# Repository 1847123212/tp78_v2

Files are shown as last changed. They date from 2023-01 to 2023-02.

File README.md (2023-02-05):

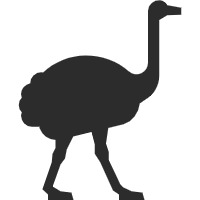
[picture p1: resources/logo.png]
MarkText


<h1 align="center">TrackPoint78 </h1>

TrackPoint78是基于CH582M的三模机械键盘方案。

V2.0新特性：

1. 支持USB U盘改键和配置

2. 支持触摸板触摸条操作

3. 集成USB hub接口

4. 增加I2C磁吸扩展口

5. 集成RF模式和接收器方案

6. 增加I2C小红点方案

7. 增加触摸条震动反馈

8. 优化OELD UI

9. 增加Fn+B进BootLoader功能

10. 增加待机自动进lowpower模式

11. ...

### 仓库目录

```mermaid
flowchart LR

A(repository) --> B(documents - 手册和文档)
A(repository) --> C(mounriver_project - wch软件工程)
A(repository) --> D(pcb_project - PCB工程)
A(repository) --> E(solidworks_project - 模型相关文件)
A(repository) --> F(tools - 相关辅助工具)
C(mounriver_project - wch软件工程) --> G(BLE_CH582M - 三模无线键盘工程)
C(mounriver_project - wch软件工程) --> H(RF_CH582M - 配套接收器工程)
C(mounriver_project - wch软件工程) --> I(CH582M - 单模USB旧工程, 用来测试)
```

### 软件工程目录

```mermaid
flowchart LR

A(BLE_582M) --> B(APP - 应用层)
A(BLE_582M) --> C(HAL - HAL层, 包含各种驱动接口)
A(BLE_582M) --> D(Ld - 链接文件)
A(BLE_582M) --> E(LIB - 存放WCH蓝牙闭源库)
A(BLE_582M) --> F(Packages - 第三方开源包)
A(BLE_582M) --> G(Profile - 蓝牙服务相关)
A(BLE_582M) --> H(RVMSIS - RISC V相关指令)
A(BLE_582M) --> I(Startup - CH582M启动文件)
A(BLE_582M) --> J(StdPeriphDriver - CH582M库函数)
```

### 关于固件升级Q&A

- **Q**: 如何进入BOOTLOADER？

- **A:** 按住底板中BOOT键通电，或按下Fn+B进入BOOTLOADER。注意：Fn+B后会擦除部分CodeFlash部分片段，上电后必须先下载程序。

- **Q:** 如何升级固件？

- **A:** 使用WCH官方ISP工具进行固件升级，工具目录：tools/WCHISPTool/WCHISPTool.exe。
  
  > - 选择CH58x系列；
  > 
  > - 在USB设备列表里找到自己的设备，若找不到尝试重新进入BOOT；
  > 
  > - 根据需求勾选相关下载配置，若不确定可进行咨询，一般使用默认配置即可；
  > 
  > - 选择用户程序文件；
  > 
  > - 最后点击下载。

- **Q:** 多次点击下载后，进度条跑完显示失败。

- **A:** 建议更换核心板。

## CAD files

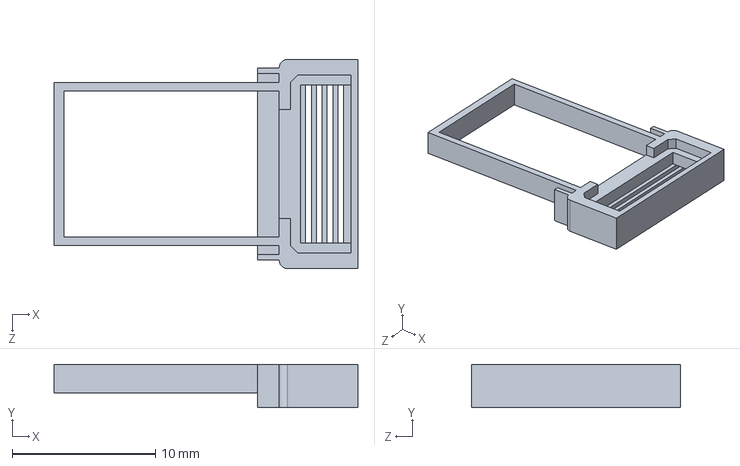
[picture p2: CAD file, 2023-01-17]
solidworks_project/RF接收器_底座.SLDPRT
21.2 x 3.00 x 14.6 mm

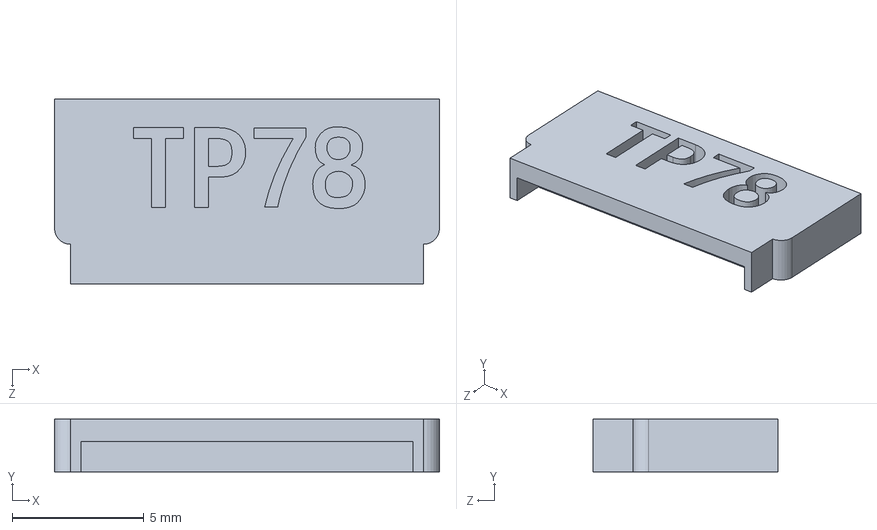
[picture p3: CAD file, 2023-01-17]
solidworks_project/RF接收器_上盖.SLDPRT
14.6 x 2.00 x 7.00 mm

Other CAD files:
solidworks_project/RF接收器_上盖.STL
solidworks_project/RF接收器_底座.STL

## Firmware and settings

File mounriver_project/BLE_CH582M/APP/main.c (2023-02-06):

/********************************** (C) COPYRIGHT *******************************
* File Name          : main.c
* Author             : ChnMasterOG, WCH
* Version            : V2.0
* Date               : 2022/11/30
* Description        : 应用层 - TP78小红点+蓝牙+2.4G三模键盘应用主函数及任务系统初始化
* Copyright (c) 2021 Nanjing Qinheng Microelectronics Co., Ltd.
* SPDX-License-Identifier: GPL-3.0
*******************************************************************************/

/********************************** (C) COPYRIGHT *******************************
 *  Pin information:
 *  PB10 & PB11 --- USB1_D-/USB1_D+; [PA0~PA7 & PA9 & PA11~PA15] & [PB0/PB1/PB2/PB3/PB5/PB6] --- KeyBoard
 *  PB15(*) & PB14 --- PS/2 Reserved; PA10 --- WS2812(TMR1); PB13 & PB12 --- SCL/SDA
 *  PA8 --- Battery ADC; PB16 & PB17 --- Battery COM/CHRG; PB7 & PB4 --- TXD0/RXD0;
 *  PB21 & PB20 ---TXD3_/RXD3_; PB15(*) --- I2C TrackPoint IRQ; PB18 --- MPR121 IRQ; PB19 --- Motor CTL
 ********************************* (C) COPYRIGHT ********************************/

/*********************************************************************
 * INCLUDES
 */
#include "HAL.h"
#include "CONFIG.h"
#include "CH58x_common.h"
#include "hiddev.h"

/*********************************************************************
 * GLOBAL TYPEDEFS
 */
__attribute__((aligned(4))) u32 MEM_BUF[BLE_MEMHEAP_SIZE/4];

#if (defined (BLE_MAC)) && (BLE_MAC == TRUE)
u8C MacAddr[6] = {0x84,0xC2,0xE4,0x03,0x02,0x02};
#endif

/*******************************************************************************
* Function Name  : Main_Circulation
* Description    : 主循环
* Input          : None
* Output         : None
* Return         : None
*******************************************************************************/
__HIGH_CODE
void Main_Circulation()
{
  // 开启TMOS任务调度
  while(1){
    TMOS_SystemProcess( );
  }
}

/*******************************************************************************
* Function Name  : main
* Description    : 主函数
* Input          : None
* Output         : None
* Return         : None
*******************************************************************************/
int main( void )
{
#if (defined (DCDC_ENABLE)) && (DCDC_ENABLE == TRUE)
  PWR_DCDCCfg( ENABLE );
#endif
  SetSysClock( CLK_SOURCE_PLL_60MHz );
#if (defined (HAL_SLEEP)) && (HAL_SLEEP == TRUE)
  GPIOA_ModeCfg( GPIO_Pin_All, GPIO_ModeIN_PU );
  GPIOB_ModeCfg( GPIO_Pin_All, GPIO_ModeIN_PU );
#endif
#ifdef DEBUG  // DEBUG = 3(use UART3)
  GPIOB_SetBits(GPIO_Pin_21);
  GPIOB_ModeCfg(GPIO_Pin_20, GPIO_ModeIN_PU);       // RXD-配置上拉输入
  GPIOB_ModeCfg(GPIO_Pin_21, GPIO_ModeOut_PP_5mA);  // TXD-配置推挽输出，注意先让IO口输出高电平
  GPIOPinRemap(ENABLE, RB_PIN_UART3);
  UART3_DefInit();
#endif
  PRINT("%s\n",VER_LIB);
  CH58X_BLEInit( );
  HAL_Init( );
#if (defined (HAL_RF)) && (HAL_RF == TRUE)
  if (g_Ready_Status.rf == FALSE) {
#endif
    GAPRole_PeripheralInit( );
    HidDev_Init( );
    HidEmu_Init( );
#if (defined (HAL_RF)) && (HAL_RF == TRUE)
  } else {
    RF_RoleInit();
    RF_Init();
  }
#endif
  tmos_start_task( halTaskID, MAIN_CIRCULATION_EVENT, 10 ); // 主循环
  tmos_start_task( halTaskID, WS2812_EVENT, 10 );  // 背光控制
  tmos_start_task( halTaskID, OLED_UI_EVENT, 10 );  // OLED UI
#if ((defined HAL_MPR121_CAPMOUSE) && (HAL_MPR121_CAPMOUSE == TRUE)) || ((defined HAL_MPR121_TOUCHBAR) && (HAL_MPR121_TOUCHBAR == TRUE))
  tmos_start_task( halTaskID, MPR121_EVENT, 10 );  // MPR121
#endif
  tmos_start_task( halTaskID, SYST_EVENT, 10 );  // 系统定时
  Main_Circulation();
}

/*******************************************************************************
* Function Name  : GPIOA_IRQHandler
* Description    : GPIOA外部中断
* Input          : None
* Return         : None
*******************************************************************************/
__INTERRUPT
__HIGH_CODE
void GPIOA_IRQHandler(void)
{
#if (defined MSG_CP) && (MSG_CP == TRUE)
  CP_WAKEUP_GPIO(SetBits)( CP_WAKEUP_PIN );   // 唤醒CP
  g_Ready_Status.cp = FALSE;
  tmos_start_task( halTaskID, CP_INITIAL_EVENT, MS1_TO_SYSTEM_TIME(300) );  // CP重新上电
#endif
  GPIOA_ClearITFlagBit(Colum_Pin_ALL);  // 用于唤醒
}

/*******************************************************************************
* Function Name  : GPIOB_IRQHandler
* Description    : GPIOB外部中断
* Input          : None
* Return         : None
*******************************************************************************/
__INTERRUPT
__HIGH_CODE
void GPIOB_IRQHandler( void )
{
#if (defined HAL_PS2) && (HAL_PS2 == TRUE)
  PS2_IT_handler();
#endif
#if (defined HAL_I2C_TP) && (HAL_I2C_TP == TRUE)
  I2C_TP_IT_handler();
#endif
}

/******************************** endfile @ main ******************************/

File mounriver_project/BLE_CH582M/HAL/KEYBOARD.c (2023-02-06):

/********************************** (C) COPYRIGHT *******************************
 * File Name          : KEYBOARD.c
 * Author             : ChnMasterOG
 * Version            : V2.0
 * Date               : 2022/12/1
 * Description        : 机械键盘驱动源文件
 * Copyright (c) 2021 Nanjing Qinheng Microelectronics Co., Ltd.
 * SPDX-License-Identifier: GPL-3.0
 *******************************************************************************/

#include "HAL.h"
#include "snake.h"

const uint32_t Row_Pin[ROW_SIZE] = {GPIO_Pin_0, GPIO_Pin_1, GPIO_Pin_2, GPIO_Pin_3, GPIO_Pin_5, GPIO_Pin_6};   //row 6 - 其它键盘布局需修改此处
const uint32_t Colum_Pin[COL_SIZE] = {GPIO_Pin_4, GPIO_Pin_5, GPIO_Pin_6, GPIO_Pin_0, GPIO_Pin_1, GPIO_Pin_2, GPIO_Pin_3,
                                      GPIO_Pin_15, GPIO_Pin_14, GPIO_Pin_13, GPIO_Pin_12, GPIO_Pin_11, GPIO_Pin_9, GPIO_Pin_7};   //colum 14 - 其它键盘布局需修改此处
//row*colum = 6*14 = 84
const uint8_t KeyArrary[COL_SIZE][ROW_SIZE] = {
        { KEY_ESCAPE,   KEY_GraveAccent,    KEY_TAB,        KEY_CapsLock,   KEY_LeftShift,  KEY_LeftCTRL }, //1
        { KEY_F1,       KEY_1,              KEY_Q,          KEY_A,          KEY_None,       KEY_LeftGUI  }, //2
        { KEY_F2,       KEY_2,              KEY_W,          KEY_S,          KEY_Z,          KEY_LeftAlt  }, //3
        { KEY_F3,       KEY_3,              KEY_E,          KEY_D,          KEY_X,          KEY_MouseL   }, //4
        { KEY_F4,       KEY_4,              KEY_R,          KEY_F,          KEY_C,          KEY_MouseM   }, //5
        { KEY_F5,       KEY_5,              KEY_T,          KEY_G,          KEY_V,          KEY_MouseR   }, //6
        { KEY_F6,       KEY_6,              KEY_Y,          KEY_H,          KEY_B,          KEY_SPACEBAR }, //7
        { KEY_F7,       KEY_7,              KEY_U,          KEY_J,          KEY_N,          KEY_None     }, //8
        { KEY_F8,       KEY_8,              KEY_I,          KEY_K,          KEY_M,          KEY_None     }, //9
        { KEY_F9,       KEY_9,              KEY_O,          KEY_L,          KEY_Comma,      KEY_None     }, //10
        { KEY_F10,      KEY_0,              KEY_P,          KEY_Semicolon,  KEY_FullStop,   KEY_RightAlt }, //11
        { KEY_F11,      KEY_Subtraction,    KEY_LSbrackets, KEY_Quotation,  KEY_Slash,      KEY_RightGUI }, //12
        { KEY_F12,      KEY_Equal,          KEY_RSbrackets, KEY_None,       KEY_None,       KEY_Fn       }, //13
        { KEY_Delete,   KEY_BACKSPACE,      KEY_NonUS_WS,   KEY_ENTER,      KEY_RightShift, KEY_RightCTRL}, //14
};  // 默认键盘布局 - 其它键盘布局需修改此处
const uint8_t Extra_KeyArrary[COL_SIZE][ROW_SIZE] = {
        { KEY_None,     KEY_None,           KEY_None,       KEY_None,       KEY_None,       KEY_None }, //1
        { KEY_None,     KEY_None,           KEY_BACKSPACE,  KEY_LeftArrow,  KEY_None,       KEY_None }, //2
        { KEY_None,     KEY_None,           KEY_UpArrow,    KEY_DownArrow,  KEY_None,       KEY_None }, //3
        { KEY_None,     KEY_None,           KEY_ENTER,      KEY_RightArrow, KEY_None,       KEY_None }, //4
        { KEY_None,     KEY_None,           KEY_PageUp,     KEY_PageDown,   KEY_Home,       KEY_None }, //5
        { KEY_None,     KEY_None,           KEY_None,       KEY_None,       KEY_End,        KEY_None }, //6
        { KEY_None,     KEY_None,           KEY_None,       KEY_None,       KEY_None,       KEY_None }, //7
        { KEY_None,     KEY_None,           KEY_None,       KEY_None,       KEY_None,       KEY_None }, //8
        { KEY_None,     KEY_None,           KEY_None,       KEY_None,       KEY_None,       KEY_None }, //9
        { KEY_None,     KEY_None,           KEY_None,       KEY_None,       KEY_None,       KEY_None }, //10
        { KEY_None,     KEY_None,           KEY_PrintScreen,KEY_None,       KEY_None,       KEY_None }, //11
        { KEY_None,     KEY_None,           KEY_None,       KEY_None,       KEY_None,       KEY_None }, //12
        { KEY_None,     KEY_None,           KEY_None,       KEY_None,       KEY_None,       KEY_None }, //13
        { KEY_None,     KEY_None,           KEY_None,       KEY_None,       KEY_None,       KEY_None }, //14
};  // 额外默认键盘布局 - 其它键盘布局需修改此处
const uint8_t Key_To_LEDNumber[COL_SIZE][ROW_SIZE] = {
        { 61,   47,   33,   20,   8,    0   }, //1
        { 62,   48,   34,   21,   0xFF, 1   }, //2
        { 63,   49,   35,   22,   9,    2   }, //3
        { 64,   50,   36,   23,   10,   0xFF}, //4
        { 65,   51,   37,   24,   11,   0xFF}, //5
        { 66,   52,   38,   25,   12,   0xFF}, //6
        { 67,   53,   39,   26,   13,   3   }, //7
        { 68,   54,   40,   27,   14,   0xFF}, //8
        { 69,   55,   41,   28,   15,   0xFF}, //9
        { 70,   56,   42,   29,   16,   0xFF}, //10
        { 71,   57,   43,   30,   17,   4   }, //11
        { 72,   58,   44,   31,   18,   5   }, //12
        { 73,   59,   45,   0xFF, 0xFF, 6   }, //13
        { 74,   60,   46,   32,   19,   7   }, //14
};  // 矩阵键盘位置转LED编号
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

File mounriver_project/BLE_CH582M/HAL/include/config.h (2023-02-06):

/********************************** (C) COPYRIGHT *******************************
 * File Name          : CONFIG.h
 * Author             : ChnMasterOG, WCH
 * Version            : V1.10
 * Date               : 2022/11/13
 * Description        : 配置说明及默认值，建议在工程配置里的预处理中修改当前值
 *******************************************************************************/

/******************************************************************************/
#ifndef __CONFIG_H
#define __CONFIG_H

#define	ID_CH582M							0x82

#define CHIP_ID								ID_CH582M

#ifdef CH57xBLE_ROM
#include "CH58xBLE_ROM.H"
#else
#include "CH58xBLE_LIB.H"
#endif
/*********************************************************************
 【MAC】
 BLE_MAC											- 是否自定义蓝牙Mac地址 ( 默认:FALSE - 使用芯片Mac地址 )，需要在main.c修改Mac地址定义

 【DCDC】
 DCDC_ENABLE                  - 是否使能DCDC ( 默认:FALSE )

 【SLEEP】
 HAL_SLEEP   									- 是否开启睡眠功能 ( 默认:FALSE )
 WAKE_UP_RTC_MAX_TIME					- 等待32M晶振稳定时间，根据不同睡眠类型取值可分为： 睡眠模式/下电模式         -	45(默认)
                                                                                                                                                                                        暂停模式					-	45
                                                                                                                                                                                        空闲模式					-	5
 
 【TEMPERATION】
 TEM_SAMPLE										- 是否打开根据温度变化校准的功能，单次校准耗时小于10ms( 默认:TRUE )
 
 【CALIBRATION】
 BLE_CALIBRATION_ENABLE				- 是否打开定时校准的功能，单次校准耗时小于10ms( 默认:TRUE )
 BLE_CALIBRATION_PERIOD				- 定时校准的周期，单位ms( 默认:120000 ) 
 
 【SNV】
 BLE_SNV    				          - 是否开启SNV功能，用于储存绑定信息( 默认:TRUE )
 BLE_SNV_ADDR    					    - SNV信息保存地址，使用data flash最后( 默认:0x77E00 )
                              - 如果配置了SNVNum参数，则需要对应修改Lib_Write_Flash函数内擦除的flash大小，大小为SNVBlock*SNVNum

 【RTC】
 CLK_OSC32K										- RTC时钟选择，如包含主机角色必须使用外部32K( 默认:0 外部(32768Hz)，1：内部(32000Hz)，2：内部(32768Hz) )

 【MEMORY】
 BLE_MEMHEAP_SIZE  						- 蓝牙协议栈使用的RAM大小，不小于6K ( 默认:(1024*6) )

 【DATA】
 BLE_BUFF_MAX_LEN							- 单个连接最大包长度( 默认:27 (ATT_MTU=23)，取值范围[27~251] )
 BLE_BUFF_NUM									- 控制器缓存的包数量( 默认:5 )
 BLE_TX_NUM_EVENT							- 单个连接事件最多可以发多少个数据包( 默认:1 )
 BLE_TX_POWER									- 发射功率( 默认:LL_TX_POWEER_0_DBM (0dBm) )
 
 【MULTICONN】
 PERIPHERAL_MAX_CONNECTION	  - 最多可同时做多少从机角色( 默认:1 )
 CENTRAL_MAX_CONNECTION				- 最多可同时做多少主机角色( 默认:3 )
 **********************************************************************/

/*********************************************************************
 * 默认配置值
 */
#ifndef FIRMWARE_VERSION
#define FIRMWARE_VERSION            "V2.0.0"
#endif
#ifndef BLE_MAC
#define BLE_MAC											FALSE
#endif
#ifndef DCDC_ENABLE
#define DCDC_ENABLE                 FALSE
#endif
#ifndef HAL_SLEEP
#define HAL_SLEEP										FALSE
#endif
#ifndef WAKE_UP_RTC_MAX_TIME
#define WAKE_UP_RTC_MAX_TIME				45
#endif
#ifndef HAL_KEY
#define HAL_KEY											FALSE         // 板载按键
#endif
#ifndef HAL_LED
#define HAL_LED											FALSE         // 板载LED
#endif
#ifndef HAL_USB
#define HAL_USB                     TRUE          // USB
#endif
#ifndef HAL_PS2
#define HAL_PS2                     FALSE         // PS/2小红点
#endif
#ifndef HAL_KEYBOARD
#define HAL_KEYBOARD                FALSE          // 键盘
#endif
#ifndef HAL_OLED
#define HAL_OLED                    TRUE          // OLED
#endif
#ifndef HAL_BATTADC
#define HAL_BATTADC                 TRUE          // 电池ADC
#endif
#ifndef HAL_WS2812_PWM
#define HAL_WS2812_PWM              TRUE          // WS2812 PWM驱动
#endif
#ifndef HAL_MOTOR
#define HAL_MOTOR                   TRUE          // 震动马达
#endif
#ifndef HAL_RF
#define HAL_RF                      TRUE          // RF 2.4G
#endif
#ifndef HAL_HW_I2C
#define HAL_HW_I2C                  TRUE          // 硬件I2C
#endif
#ifndef SW_PAINTEDEGG
#define SW_PAINTEDEGG               TRUE          // 彩蛋
#endif
#ifndef HAL_I2C_TP
#define HAL_I2C_TP                  TRUE         // I2C小红点
#endif
#ifndef HAL_MPR121_CAPMOUSE
#define HAL_MPR121_CAPMOUSE         FALSE          // MPR121触摸板
#endif
#ifndef HAL_MPR121_TOUCHBAR
#define HAL_MPR121_TOUCHBAR         FALSE          // MPR121触摸条
#endif
#ifndef MSG_CP
#define MSG_CP                      FALSE          // CP通讯
#endif
#ifndef TEM_SAMPLE
#define TEM_SAMPLE									TRUE          // 温度采样
#endif
#ifndef BLE_CALIBRATION_ENABLE
#define BLE_CALIBRATION_ENABLE			TRUE          // BLE校准
#endif
#ifndef BLE_CALIBRATION_PERIOD
#define BLE_CALIBRATION_PERIOD			120000        // BLE校准周期
#endif
#ifndef BLE_SNV
#define BLE_SNV											TRUE
#endif
#ifndef BLE_SNV_ADDR
#define BLE_SNV_ADDR								0x77E00-FLASH_ROM_MAX_SIZE
#endif
#ifndef CLK_OSC32K
#define CLK_OSC32K									2							// 该项请勿在此修改，必须在工程配置里的预处理中修改，如包含主机角色必须使用外部32K
#endif
#ifndef BLE_MEMHEAP_SIZE
#define BLE_MEMHEAP_SIZE						(1024*6)
#endif
#ifndef BLE_DEVICE_NUM
#define BLE_DEVICE_NUM              6             // 记住蓝牙主机设备数目
#endif
#ifndef BLE_BUFF_MAX_LEN
#define BLE_BUFF_MAX_LEN						27
#endif
#ifndef BLE_BUFF_NUM
#define BLE_BUFF_NUM								5
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

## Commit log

2022-11-30 1. update pin information descriptions in main.c 2. adjust indents in main.c, PS2.c and PS2.h 3. update I/O macros in PS2.h 4. add hardware I2C driver: HW_I2C.c & HW_I2C.h 5. modify OLED.c and OLED.h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
2023-01-07 1. adjust indents in OLED.c 2. modify row pin definitions of KEYBOARD.c 3. update newest CH582M stdperiphdriver 4. add MSG_CP codes 5. add 0.42 and 0.66 OLED_Init codes 6. modify ISP.c/ISP.h to CORE.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
    [CORE.c, HAL.h, HW_I2C.c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]
2023-01-17 1. modify sleep mode to pd mode 2. improve the capmouse algorithm 3. add some configurations
    [RF接收器_上盖.SLDPRT, RF接收器_上盖.STL, RF接收器_底座.SLDPRT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]
2023-02-04 1. ported the CherryUSB driver code 2. ported the FatFs driver code 3. optimized the RAM zone 4. CodeFlash zone now is used for U-disk
2023-02-05 1. croped some unused files 2. add some introduction 3. update dataflash read/write api
    [CH582SCH_2021-12-11.schdoc, RF接收器.SLDPRT, RF接收器_a.SLDPRT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]
2023-02-06 1. optimized the RAM zone 2. add USB vol control 3. fix a USB HID bug
    [HAL.h, I2C_TP.c, KEYBOARD.c]
